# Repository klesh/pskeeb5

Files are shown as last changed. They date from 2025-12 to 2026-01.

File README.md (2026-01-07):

# pskeeb5

A keyboard crafted for uncompromising typists who value efficiency and ergonomics.

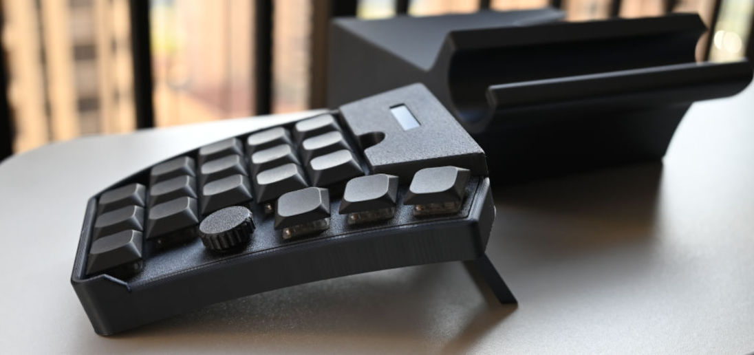
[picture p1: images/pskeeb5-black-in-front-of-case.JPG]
pskeeb5

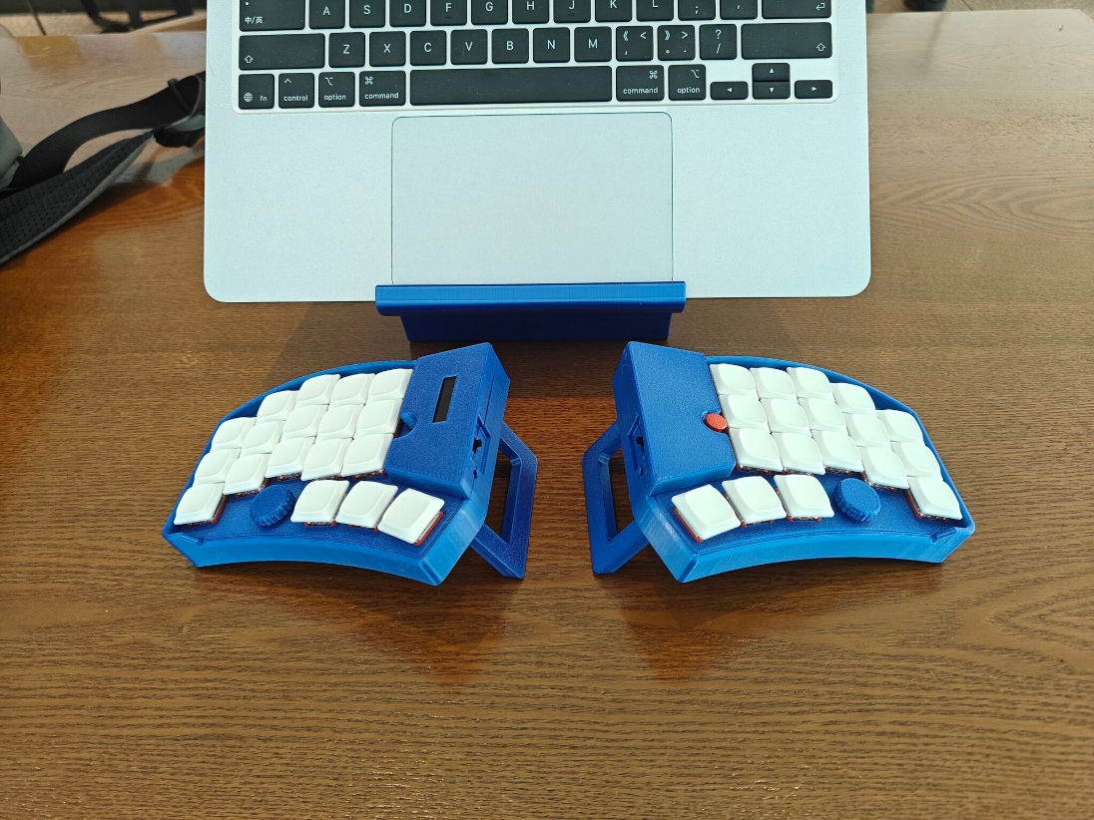
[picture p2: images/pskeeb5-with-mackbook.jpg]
pskeeb5

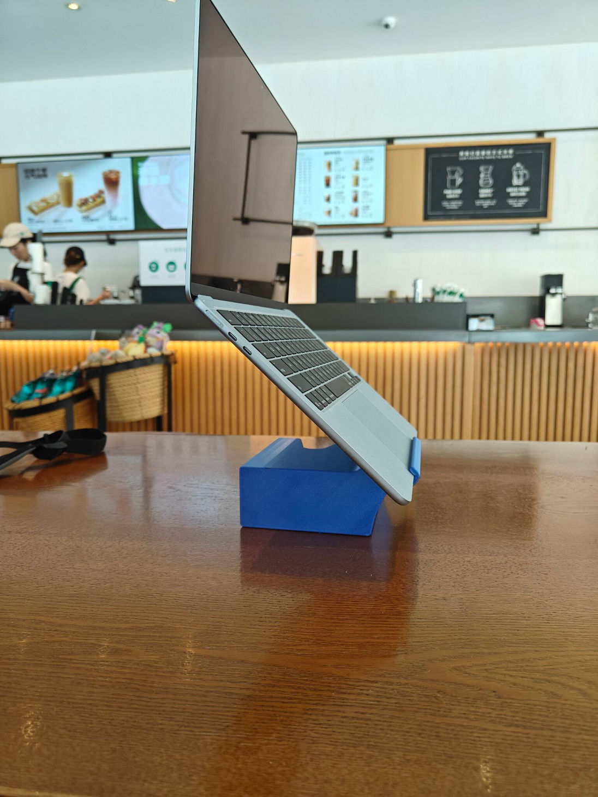
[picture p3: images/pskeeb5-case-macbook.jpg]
pskeeb5


- **Ergonomic Split & Tilted Design**: Promotes natural hand posture.
- **Dual-Purpose Travel Case**: Protects your keyboard and transforms into a laptop riser.
- **Wireless Freedom**: Bluetooth connectivity for a clean setup.
- **Precision Control**: Integrated Trackpoint with adjustable sensitivity.
- **Travel-Ready**: Dedicated power switch to preserve battery life on the go.
- **Status at a Glance**: OLED displays on both halves for instant feedback.

## Build Guide

### Step 1: BOM Preparation

1. Download the latest gerber zip file in the [pcb](pcb) folder and place an order with a **PCB thickness of 1.6mm**.
2. Make sure you have all components described in the [bom](bom) README.md ready.

### Step 2: Print the Case

1. Download the latest case 3D printing files in the [case](case) directory.
2. Print all plates. Note that the top plate must use a finer printing quality to ensure a proper fit with other components.

### Step 3: Soldering

video: https://youtu.be/shT9tNO009Q?si=PsniRqzwwflS7J1r
Firmwares can be downloaded from the releases page.

### Step 4: Assembling, Flash Firmware & Test

https://youtu.be/UxQ_yc_v1pM

### Step 5: Configurator - ZMK Studio

*Video guide coming soon.*

# License
This work is licensed under a Creative Commons Attribution-NonCommercial-ShareAlike 4.0 International License.

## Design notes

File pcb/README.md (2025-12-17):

# PCB Design

Preview of the PCB layout.

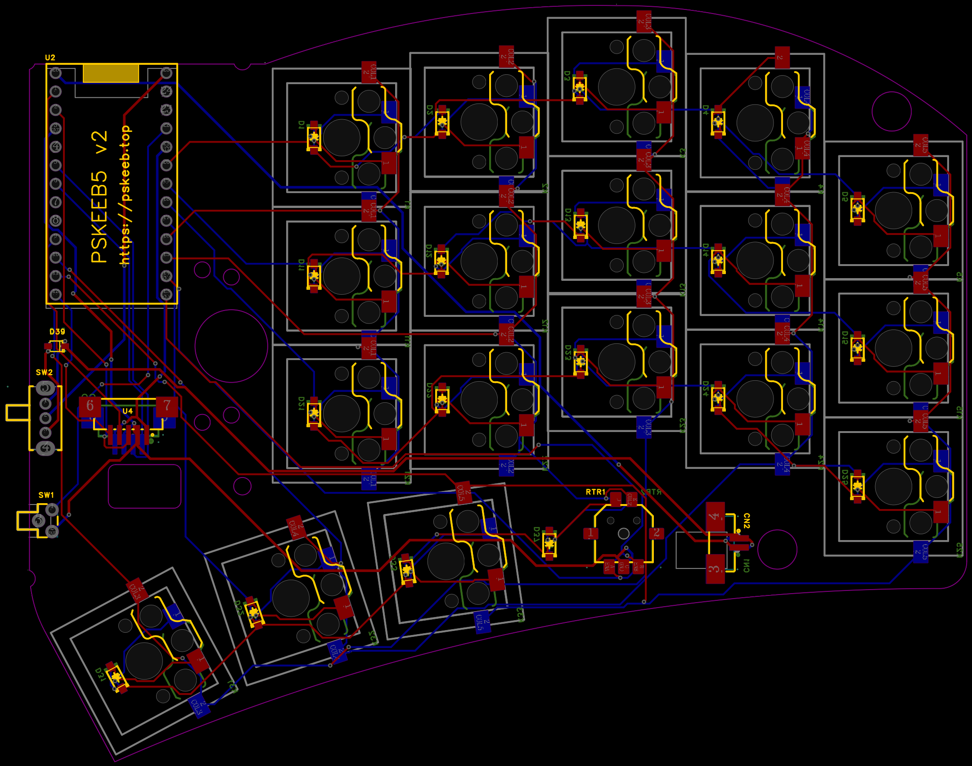
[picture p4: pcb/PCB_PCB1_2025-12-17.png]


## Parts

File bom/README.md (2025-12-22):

# BOM

| Component | Model | Quantity | Reference Photo |
| :--- | :--- | :--- | :--- |
| PCB | ... | 2 pcs | |
| CASE | ... | 1 set | |
| Micro Controller | nice!nano V2.0 | 2 pcs | |
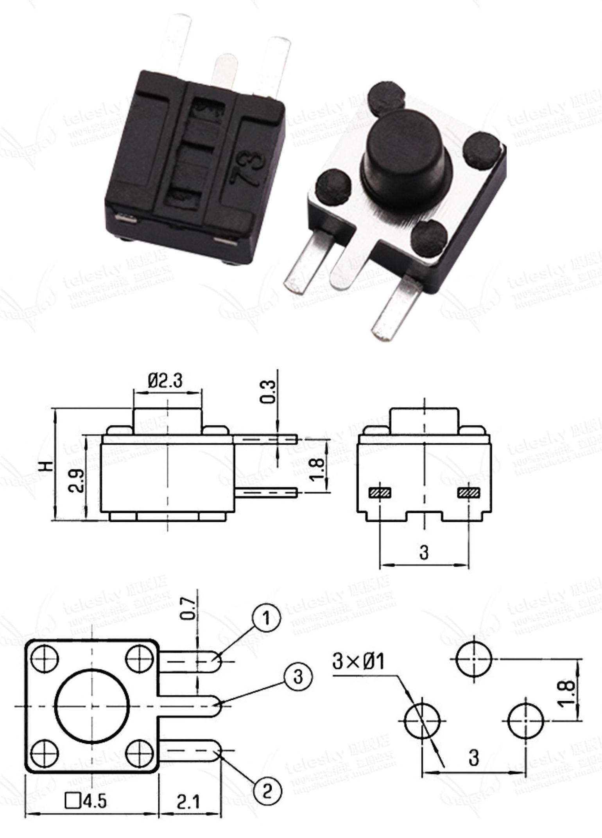
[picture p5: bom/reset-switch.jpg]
| Reset Switch | 4.5x4.5x5mm 3P | 2 pcs |  |
| Power Switch | SK-12D07VG3 3P2S 3mm H | 2 pcs |  |
| Pin Header | 0.64x0.64x5.0mm | 52 pcs |
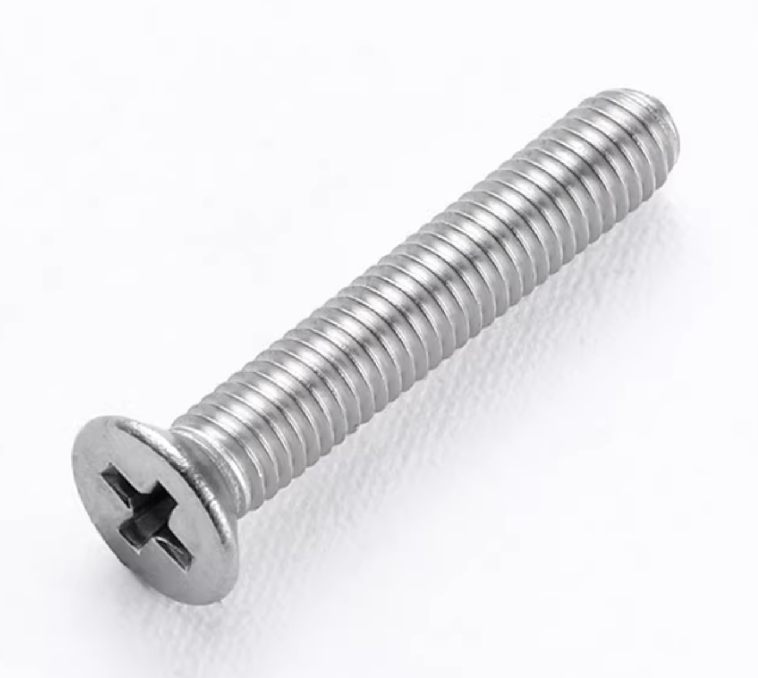
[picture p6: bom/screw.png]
| Case Screws | Countersunk M2x12 | 4 pcs |  |
| Cover Screws | Countersunk M2x16 | 8 pcs |  |
| Trackpoint Screws | Countersunk M2x8 | 4 pcs |  |
| OLED Screws | Countersunk M2x4 | 1 pc |  |
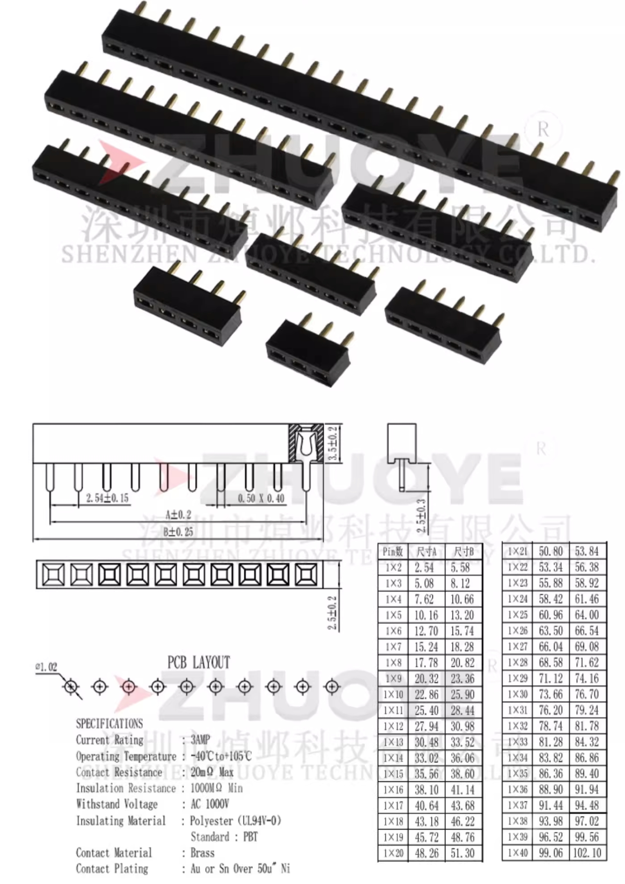
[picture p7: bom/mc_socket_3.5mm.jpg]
| Micro Controller Socket | 2.54mmx13pin 3.5H | 4 pcs |  |
| Trackpoint Socket | GH 1.25mmx5pin Vertical SMB | 1 pc |
| OLED Socket | GH 1.25mmx4pin Vertical SMB | 1 pc |
| Trackpoint Cable | GH1.25 5pin 100mm | 1 pc |
| OLED Cable | GH1.25 4pin 100mm | 1 pc |
| Key Switch Socket | Kailh Choc Hotswap Socket | 36 pcs |
| Key Switch | Kailh Choc v1 or v2 | 36 pcs |
| Key Cap | Kailh Choc v1 or MX style low profile (v2) key cap | 36 pcs |
| Charging Diode | 1N5819 SOD-323 SS14 | 2 pcs |
| Key Switch Diode | 1N4148 SOD123 1206 | 36 pcs |
| OLED | 0.91inch 128x32 I2C 4pin | 1 pc |
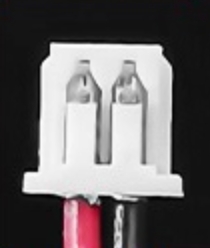
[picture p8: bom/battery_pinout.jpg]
| Battery | 3.7v Rechargeable Lithium battery 523450 1050mA 1.25 positive pinout | 2 pcs |  |
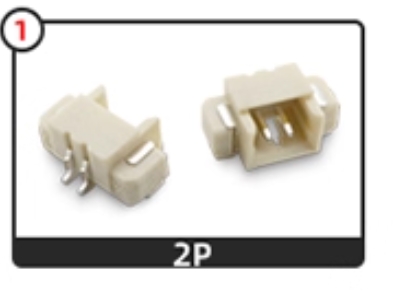
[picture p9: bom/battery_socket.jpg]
| Battery Socket | 1.25 Horizontal SMB | 2 pcs |  |
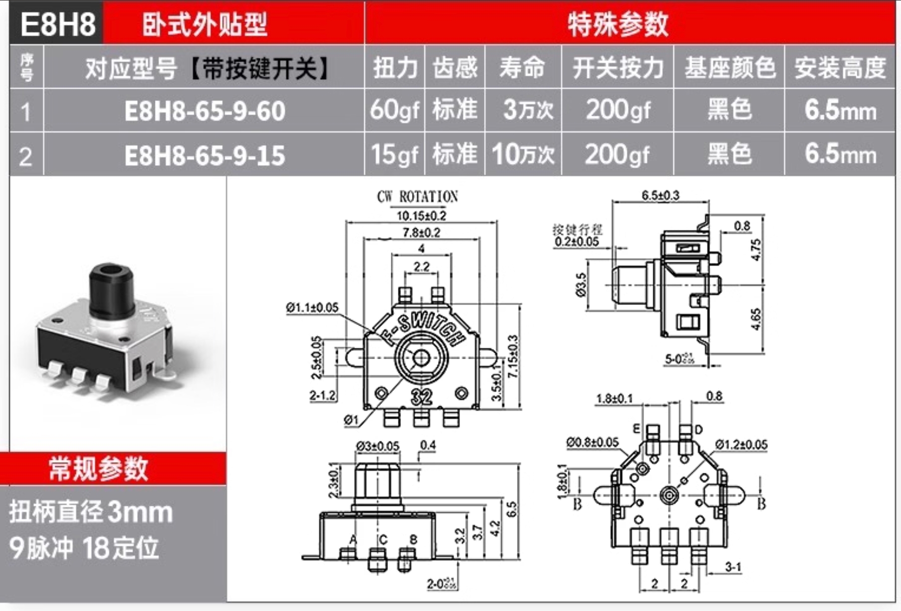
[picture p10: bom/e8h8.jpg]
| Rotary Encoder | E8H8 7.5mm 30g Encoder with Button | 2 pcs |  |
| Trackpoint | ThinkPad trackpoint PTPM754DR | 1 pc |

# Trackpoint

1. Find a trackpoint module that looks similar to the following one. You may find them in old ThinkPad Laptop Keyboards.
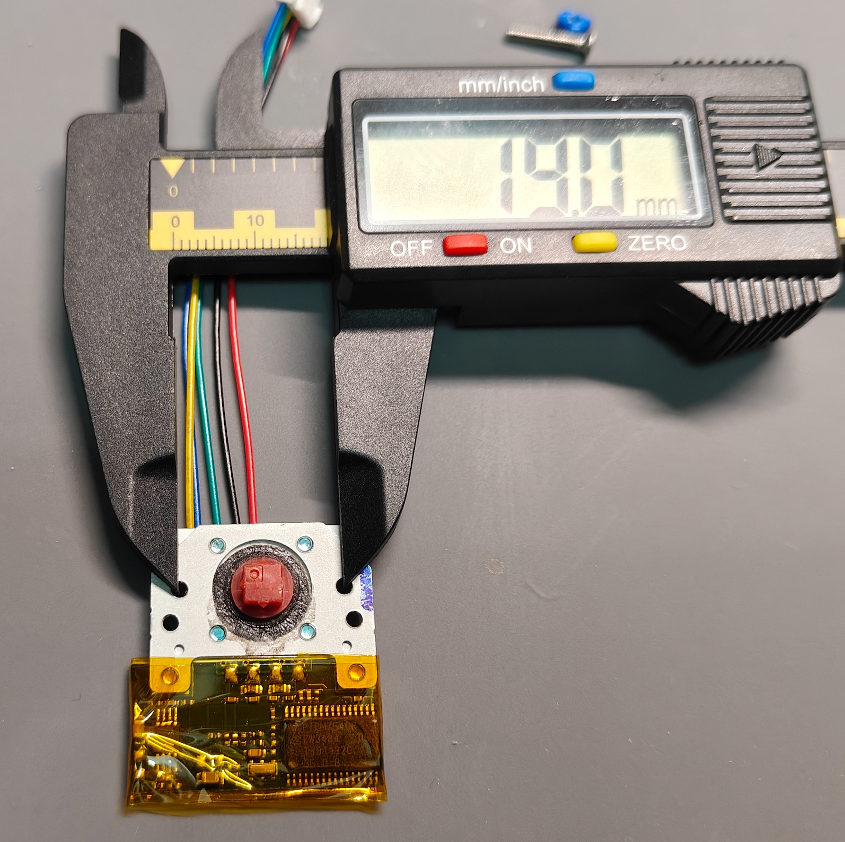
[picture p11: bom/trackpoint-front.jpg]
  
2. Solder the GH1.25 Cable in the order shown in the following photo.
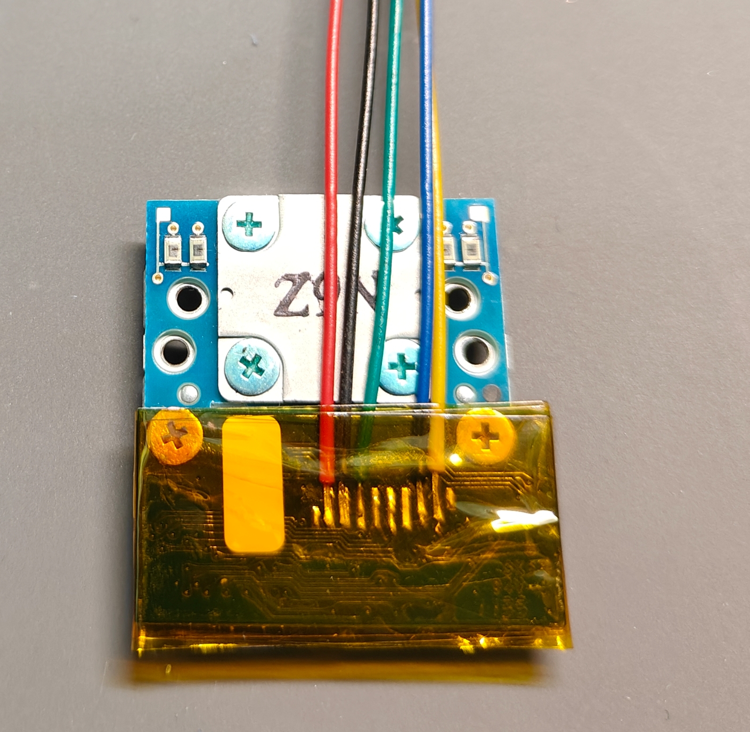
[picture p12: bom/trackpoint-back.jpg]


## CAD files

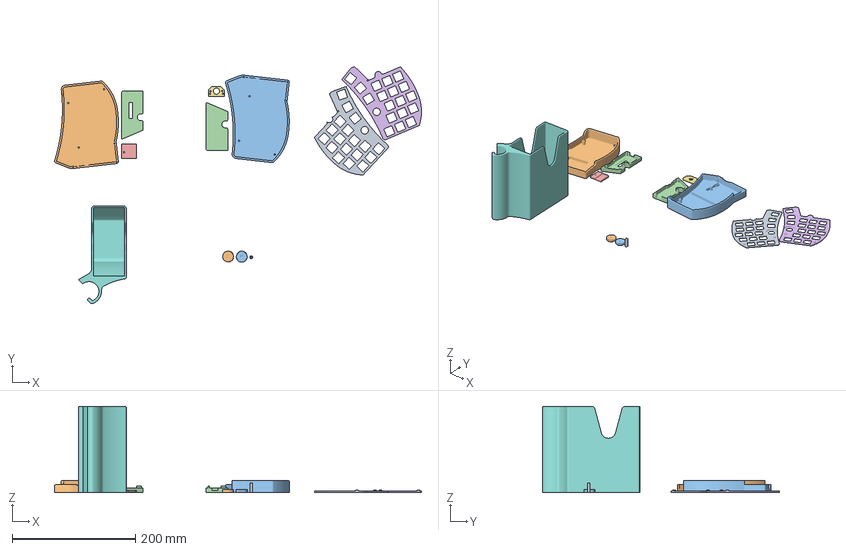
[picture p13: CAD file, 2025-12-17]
case/pskeeb5-v2.3mf
594.8 x 384.6 x 140.0 mm
Assembly x 2

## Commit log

2025-12-22 fix: gh sockets are veritical
2025-12-26 feat: added soldering video
2025-12-26 fix: remove soldering video thumbnail
2026-01-07 docs: update assembling video
